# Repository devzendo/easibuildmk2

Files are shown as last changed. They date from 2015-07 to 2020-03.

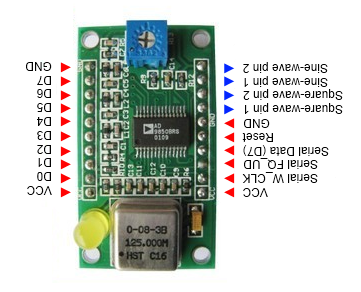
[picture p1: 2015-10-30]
docs/AD9850Pinout.png

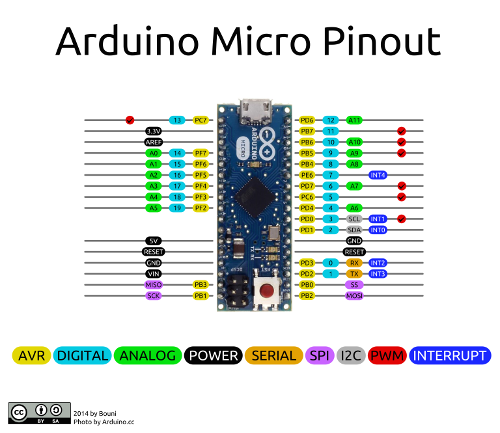
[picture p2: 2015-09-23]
docs/Arduino Micro Pinout Small.png

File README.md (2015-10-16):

# EasiBuild Mk II

This repository contains code and documentation for the EasiBuild Mk II low
power (QRP) amateur radio Morse code (CW: Continuous Wave) transceiver designed
by Matt Gumbley M0CUV based on an earlier design by Bruce Edwards G3WCE.

See https://mattgumbley.wordpress.com/category/amateur-radio/easibuild-mk-2/ for
the full set of blog articles on this project.

The code, diagrams, schematics and articles in this project are all licensed
under the Apache Public License, v2.

The Arduino IDE libraries in the Libraries folder are licensed under their own
licenses, please check the zip files there, and their respective websites,
details of which you'll find in the EasiBuildMk2.ino file.

To set up the libraries in the Arduino IDE:
1) SCoop. Create a folder called SCoop in your Arduino IDE's libraries folder
   (e.g. mine is ~/Documents/Arduino/libraries on OSX). Extract the 'SCoop V1.2
   New Year Pack.zip' file to a temporary folder, then copy SCoop/SCoop.{cpp|h}
   into the libraries/SCoop folder you created.
2) LiquidCrystal - can be added as a .zip library.
3) EnableInterrupt - don't know yet....

73 de M0CUV

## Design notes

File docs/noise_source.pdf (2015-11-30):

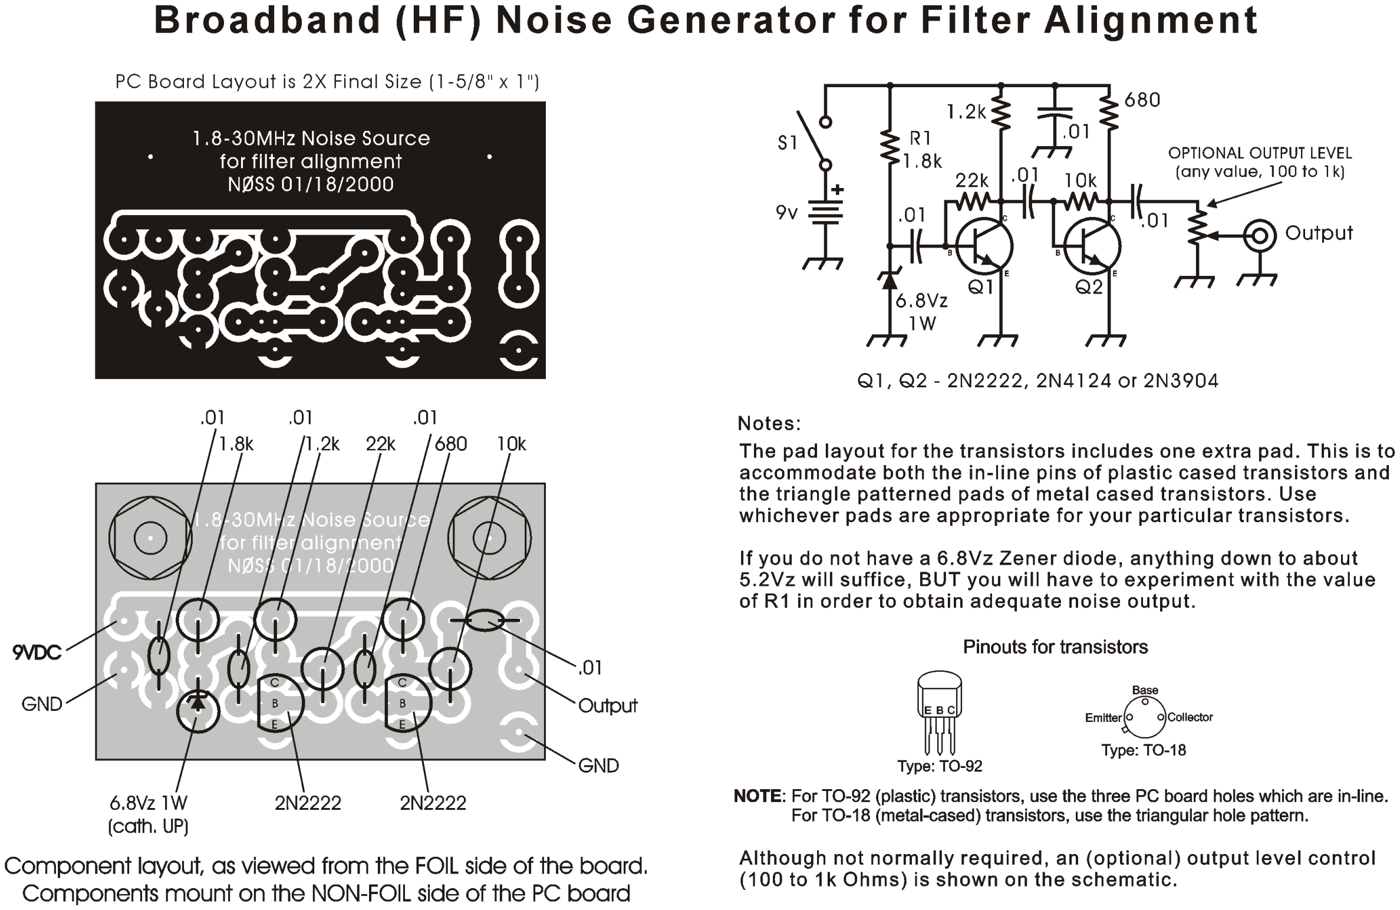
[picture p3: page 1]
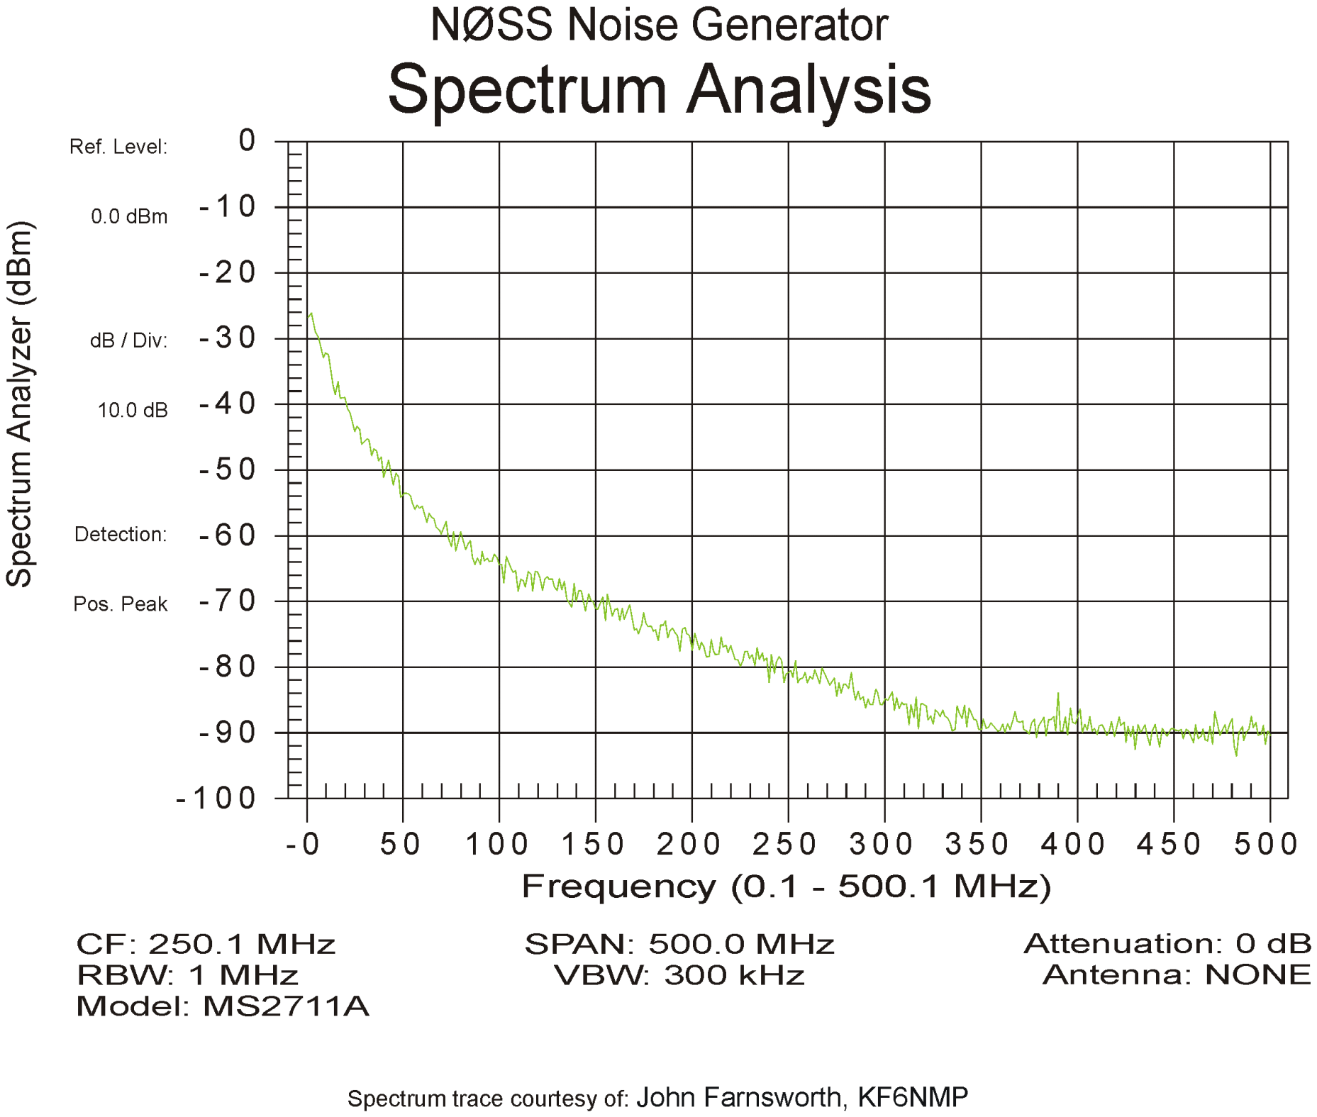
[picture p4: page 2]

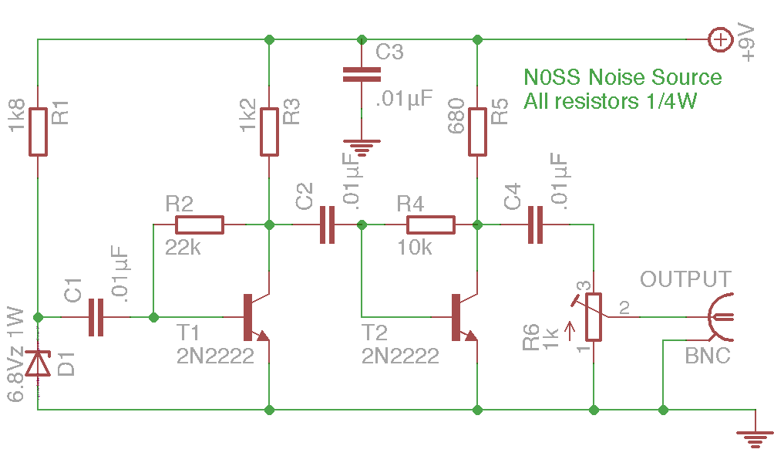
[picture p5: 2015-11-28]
docs/noise-source-schematic.png

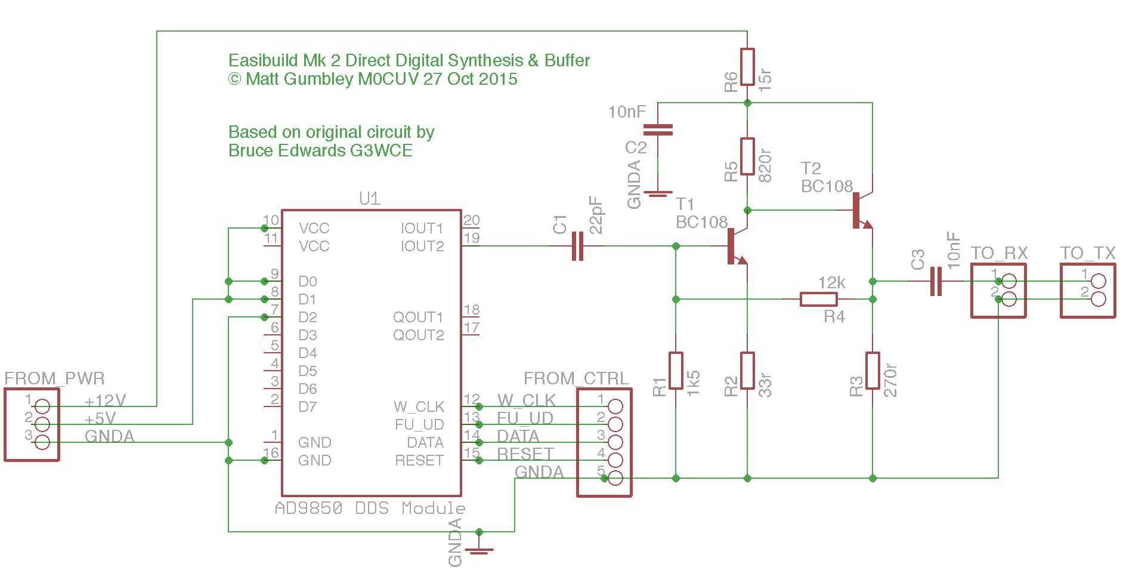
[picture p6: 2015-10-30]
docs/dds-schematic.png

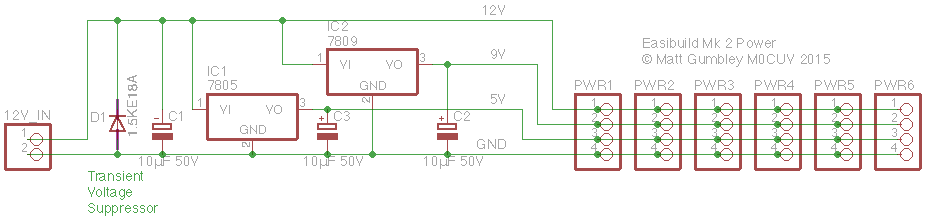
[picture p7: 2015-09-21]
docs/power-schematic.png

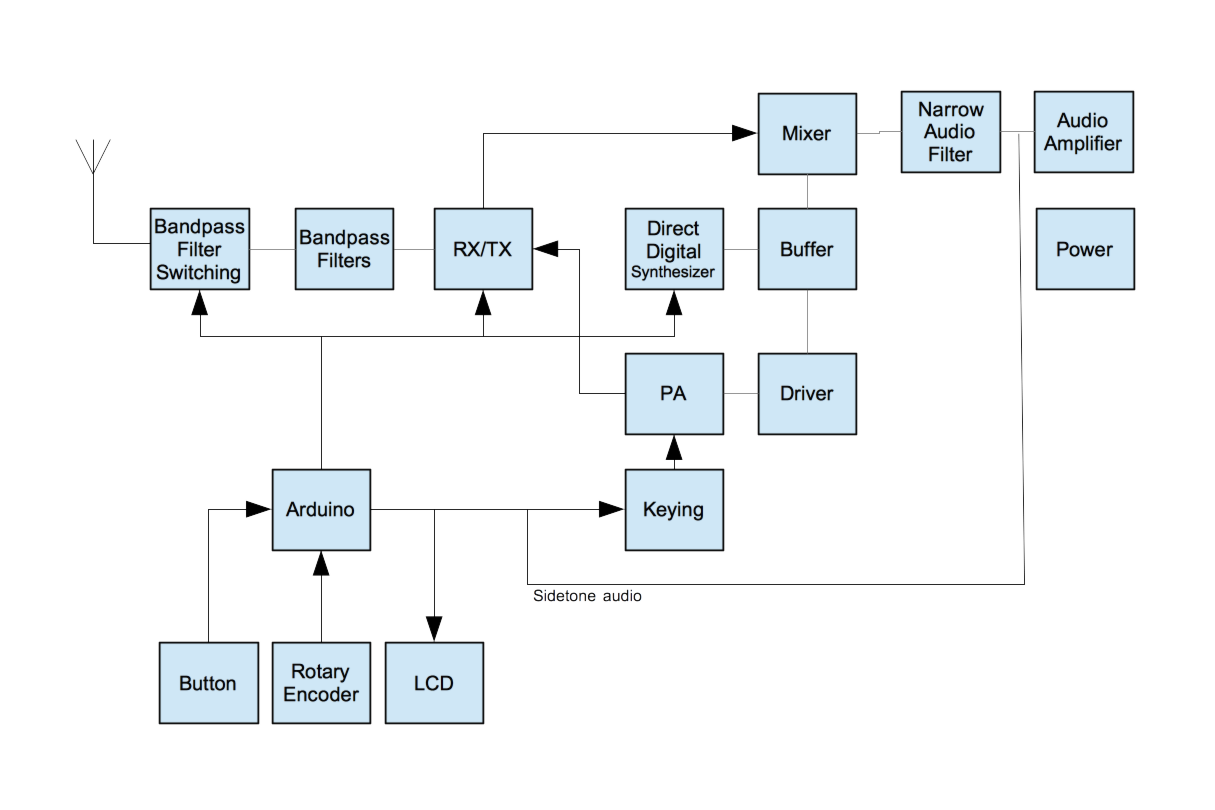
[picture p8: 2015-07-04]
docs/Overview Diagram.png

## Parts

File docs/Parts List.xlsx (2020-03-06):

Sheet: EasiBuild Mk 2
EasiBuild Mark 2 Parts | Orig EB part | Mk2 part | Supplier | Cost | Quantity | Total | Notes | URL
 |  |  |  |  |  | #N/A
Control & VFO:
Arduino Micro |  |  | Amazon/4tronix | £15.12 | 1 | £15.12 |  | http://4tronix.co.uk/store/index.php?rt=product/product&product_id=122
PEC16-4020F-S0024 |  |  | Mouser | £1.02 | 1 | £1.02 | Rotary encoder Mike N2HTT uses Bourns PEC16-4020F-S0024 Mouser 652-PEC16-4020FS0024 | http://uk.mouser.com/ProductDetail/Bourns/PEC16-4020F-S0024/
Silver metal knob |  |  | Proto-pic | £1.07 | 1 | £1.07 |  | http://proto-pic.co.uk/silver-metal-knob-14x24mm/
LCD |  |  | Amazon/inspiredeal limited | £1.19 | 1 | £1.19 |  | http://proto-pic.co.uk/serial-enabled-16x2-lcd-white-on-black-5v/
LCD SPI/I2C interface |  |  | Amazon/hielec | £1.10 | 1 | £1.10
Momentary tactile push button switch + cap |  |  | Amazon/sourcingmap | £0.24 | 0 | £0.00
16k 0.25W |  |  | Mouser | £0.09 | 1 | £0.09 | For PWM RC network to audio amp
10nF polyester |  |  | Mouser | £0.16 | 1 | £0.16 | For PWM RC network to audio amp
M20-7821046 |  |  |  | £0.11 | 6 | £0.66 | 10 pin female SIL socket (2 for DDS, 4 for Arduino)
74HC595 |  |  |  | £0.41 | 0 | £0.00
AD9850 DDS |  |  | eBay | £7.45 | 1 | £7.45 | From UK seller etang-uk
Buffer (not building this version): |  |  |  |  |  |  | number required when I build it v
22pF polystyrene | C5 |  |  | £0.00 | 0 | £0.00 | 1
BC108 | TR2 |  | Stock | £0.00 | 0 | £0.00 | 2
1k5 0.6W metal film | R5 |  |  | £0.10 | 0 | £0.00 | 1
10nF ceramic | C8 |  | Velleman | £0.10 | 0 | £0.00 | 2
15r 0.6W metal film | R3 |  |  | £0.10 | 0 | £0.00 | 1
820r 0.6W metal film | R4 |  |  | £0.10 | 0 | £0.00 | 1
33r 0.6W metal film | R6 |  |  | £0.10 | 0 | £0.00 | 1
12k 0.6W metal film | R7 |  |  | £0.10 | 0 | £0.00 | 1
270r 0.6W metal film | R8 |  |  | £0.10 | 0 | £0.00 | 1
Power supply:
Power coaxial jack |  |  | Mouser | £2.32 | 1 | £2.32 | Mouser 163-4304 - look elsewhere, maybe cheaper? Maplin JK09K £2.29 Proto-pic PPADA610 £2.71
Power mating plug |  |  | Mouser | £0.99 | 1 | £0.99 | Mouser 1710-2131 Maplin HH60Q is £1.99
10uF 50V elec |  |  | Stock | £0.00 | 3 | £0.00
LM7805CT |  |  |  | £0.48 | 1 | £0.48 | RS 671-0309
L7809CV |  |  | Stock | £0.00 | 1 | £0.00 | Farnell 1087089
1.5KE18ARL4G |  |  |  | £0.42 | 1 | £0.42
100nF ceramic | C43 |  | Velleman | £0.07 | 1 | £0.07 | Decoupling
5x20mm fuse holder |  |  |  | £0.70 | 1 | £0.70
1A Fuse |  |  |  | £0.13 | 1 | £0.13
Bandpass filter 160m/1.8MHz: | #REF!
x T50-2 |  |  |  | #N/A | 3 | #N/A
x 430pF close |  |  |  | #N/A | 2 | #N/A
x 560pF close |  |  |  | #N/A | 1 | #N/A
x 1800pF close |  |  |  | #N/A | 2 | #N/A
Bandpass filter 80m/3.5MHz: | #REF!
x T50-2 |  |  |  | #N/A | 3 | #N/A
x 130pF close |  |  |  | #N/A | 2 | #N/A
x 150pF close |  |  |  | #N/A | 1 | #N/A
x 910pF close |  |  |  | #N/A | 2 | #N/A
Bandpass filter 60m/5MHz: | #REF!
x T50-2 |  |  |  | #N/A | 3 | #N/A
x 47pF close |  |  |  | #N/A | 2 | #N/A
x 51pF close |  |  |  | #N/A | 1 | #N/A
x 620pF close |  |  |  | #N/A | 2 | #N/A
Bandpass filter 40m/7MHz: | £0.76
T50-2 |  |  |  | £0.14 | 3 | £0.43
39pF close |  |  |  | £0.15 | 2 | £0.31
39pF close |  |  |  | £0.15 | 1 | £0.15 | Should be 43pF but can't get those, so use 39pF + 4pF (1.5pF to 5pF) trimmer
1.5pF to 5pF Trimmer |  |  |  | £0.47 | 1 | £0.47
470pF close |  |  |  | £0.16 | 2 | £0.32
Bandpass filter 30m/10MHz: | £0.73
T50-2 |  |  |  | £0.14 | 3 | £0.43
16pF close |  |  |  | £0.21 | 3 | £0.63
330pF close |  |  |  | £0.15 | 2 | £0.29
Bandpass filter 20m/14MHz: | £0.94
T50-6 |  |  |  | £0.22 | 3 | £0.66
16pF close |  |  |  | £0.21 | 2 | £0.42
18pF close |  |  |  | £0.07 | 1 | £0.07
2.3pF to 27pF Trimmer |  |  |  | £1.79 | 1 | £1.79
220pF close |  |  |  | £0.14 | 2 | £0.28 | Should be 240pF but can't get those, so use 220pF + 20pF (2.3pF to 27pF) trimmer
Bandpass filter 17m/18MHz: | #N/A
x T50-6 |  |  |  | #N/A | 3 | #N/A
x 20pF close |  |  |  | #N/A | 2 | #N/A
x 24pF close |  |  |  | #N/A | 1 | #N/A
x 180pF close |  |  |  | #N/A | 2 | #N/A
Bandpass filter 15m/21MHz: | #N/A
x T50-6 |  |  |  | #N/A | 3 | #N/A
x 15pF close |  |  |  | #N/A | 2 | #N/A
x 16pF close |  |  |  | #N/A | 1 | #N/A
x 160pF close |  |  |  | #N/A | 2 | #N/A
Bandpass filter 12m/24MHz: | #N/A
x T50-6 |  |  |  | #N/A | 3 | #N/A
x 11pF close |  |  |  | #N/A | 2 | #N/A
x 12pF close |  |  |  | #N/A | 1 | #N/A
x 130pF close |  |  |  | #N/A | 2 | #N/A
Bandpass filter 10m/28MHz: | #N/A
x T50-6 |  |  |  | #N/A | 3 | #N/A
x 12pF close |  |  |  | #N/A | 2 | #N/A
x 13pF close |  |  |  | #N/A | 1 | #N/A
x 120pF close |  |  |  | #N/A | 2 | #N/A
Bandpass filter/T/R switching:
27k 0.25W |  |  |  | £0.08 | 1 | £0.08 | T/R: To reduce current from opto to transistor; coil resistance is 540r
270k 0.25W |  |  |  | £0.09 | 1 | £0.09 | T/R: Pull-down to prevent spurious triggering - 10x the base current resistor
13k 0.25W |  |  |  | £0.07 | 3 | £0.21 | Band: To reduce current from opto to two transistors; coil resistance is 540r
130k 0.25W |  |  |  | £0.09 | 3 | £0.28 | Band: Pull-down to prevent spurious triggering - 10x the base current resistor
470r 0.6W metal film |  |  |  | £0.10 | 5 | £0.49 | Band, T/R: From Arduino out to opto diode
4N25 |  |  |  | £0.31 | 5 | £1.55 | Band, T/R: Opto to control relay
DIP-6-Socket |  |  |  | £0.16 | 5 | £0.82
1N4001 |  |  |  | £0.02 | 7 | £0.14 | To prevent back e.m.f. from relay coil
BC547B |  |  |  | £0.05 | 7 | £0.35 | Band, T/R: each band has 2 relays (2x3) plus one for T/R
V23105A5006A201 |  |  |  | £1.34 | 7 | £9.38 | 9v, 150mW, coil resistance 540Ohm, DPDT
Mixer:
NE612 | IC3 |  |  | £1.88 | 1 | £1.88 | In a pack of 2 | http://uk.rs-online.com/web/p/up-down-converter-mixer-circuits/7257613/
DIP-8-socket |  |  | Stock | £0.00 | 1 | £0.00
100pF ceramic | C13 |  | Velleman | £0.00 | 1 | £0.00 | Ceramic plate
10nF ceramic | C14,C17,C20,C21 |  | Velleman | £0.10 | 4 | £0.39 | Ceramic disc - wonder if C17 should be polyester as it's audio?
22pF polystyrene | C15 |  |  | £0.00 | 1 | £0.00 | Polystyrene
1uF 16V elec | C16 |  |  | £0.02 | 1 | £0.02 | 16V electrolytic
1mH | RFC2 |  |  | £0.12 | 1 | £0.12
78L08 | IC2 |  | Stock | £0.00 | 1 | £0.00 | 8v? Supply
Hi-Per-Mite filter/amplifier:
100nF ceramic | C1,C10,C11,C15 |  | Velleman | £0.07 | 4 | £0.26 | Ceramic 104
1nF polyester | C4,C6,C9 |  |  | £0.18 | 3 | £0.54 | Polyester .001u or 1n0
220uF 16V elec | C12,C13,C14 |  |  | £0.06 | 3 | £0.18 | Elec
2n2 polyester | C7,C8 |  |  | £0.16 | 2 | £0.32 | Polyester .0022u
10pF ceramic | C16 |  | Velleman | £0.00 | 1 | £0.00 | Ceramic
47nF polyester | C2 |  |  | £0.16 | 1 | £0.16 | Polyester .047u
39nF polyester | C5 |  |  | £0.25 | 1 | £0.25 | Polyester .039u
36nF polyester | C3 |  |  | £1.85 | 1 | £1.85 | Polyester .036u
33k 5% | R1 |  |  | £0.08 | 1 | £0.08 | 5% resistors, these are for 640Hz
36k 5% | R2 |  |  | £0.09 | 1 | £0.09
1M 5% | R3 |  |  | £0.07 | 1 | £0.07
51k 5% | R4,R5 |  |  | £0.08 | 2 | £0.16
39k 5% | R6,R7 |  |  | £0.07 | 2 | £0.14
11k 5% | R8 |  |  | £0.07 | 1 | £0.07
820k 5% | R9 |  |  | £0.09 | 1 | £0.09
10r 5% | R10 |  |  | £0.07 | 1 | £0.07
10k 5% | R14 |  |  | £0.07 | 1 | £0.07
100k log pot + switch |  |  |  | £0.63 | 1 | £0.63
TLC274CN |  |  |  | £0.69 | 1 | £0.69
LM386 |  |  |  | £0.66 | 1 | £0.66
DIP-14-socket |  |  | Stock | £0.00 | 1 | £0.00
DIP-8-socket |  |  | Stock | £0.00 | 1 | £0.00
Transmitter:
10nF ceramic | C27,C28,C30,C31,C32 |  | Velleman | £0.10 | 5 | £0.49
1k 0.6W metal film | R15 |  |  | £0.10 | 1 | £0.10
220r 0.6W metal film | R16 |  |  | £0.10 | 1 | £0.10
BFY51 | TR5,TR6 |  | Stock | £0.00 | 2 | £0.00
56r 0.6W metal film | R18 |  |  | £0.10 | 1 | £0.10
47r 0.6W metal film | R17 |  |  | £0.10 | 1 | £0.10
T50-2 | L2 |  |  | £0.14 | 1 | £0.14
150pF ceramic | C29 |  |  | £0.02 | 1 | £0.02
2u2 ceramic | C36 |  |  | £1.79 | 1 | £1.79
33r 0.6W metal film | R19 |  |  | £0.10 | 1 | £0.10
2N2905 | TR7 |  | Stock | £0.00 | 1 | £0.00
FB | RFC3 |  | Stock | £0.00 | 1 | £0.00
1k 0.6W metal film | R20 |  |  | £0.10 | 1 | £0.10
4N25 |  |  |  | £0.31 | 1 | £0.31
TO-39 Heatsink |  |  |  | £0.30 | 1 | £0.30
DIP-6-Socket |  |  |  | £0.16 | 1 | £0.16
470r 0.6W metal film |  |  |  | £0.10 | 1 | £0.10 | From Arduino out to opto diode
PVC covererd link wire |  |  | Stock | £0.00 | 1 | £0.00
0.56mm wire |  |  | Stock | £0.00 | 1 | £0.00
0.375mm wire |  |  | Stock | £0.00 | 1 | £0.00
Miscellaneous:
Nuts, Bolts |  |  |  |  |  | £0.00
Enclosure |  |  |  |  |  | £0.00
Matrix board |  |  |  |  |  | £0.00
Stripboard |  |  |  |  |  | £0.00
3.5mm stereo socket |  |  |  | £0.45 | 2 | £0.90 | For key/paddle, and audio out | http://uk.mouser.com/ProductDetail/Kobiconn/161-3402-E/?qs=sGAEpiMZZMv0W4pxf2HiV4Mt5ZQSVq1hAasLUHlfK30%3d
BNC socket |  |  |  | £0.85 | 1 | £0.85
N0SS Noise Generator:
Enclosure |  |  |  |  |  | £0.00
On/Off Switch |  |  |  |  |  | £0.00
PP3 Battery Connector |  |  |  |  |  | £0.00
1k8 0.25W |  |  |  | £0.08 | 1 | £0.08
1k2 0.25W |  |  |  | £0.08 | 1 | £0.08
680r 0.25W |  |  |  | £0.08 | 1 | £0.08
22k 0.25W |  |  |  | £0.08 | 1 | £0.08
10k 0.25W |  |  |  | £0.07 | 1 | £0.07
1k preset |  |  | Stock | £0.00 | 1 | £0.00
10nF ceramic |  |  | Stock | £0.10 | 4 | £0.39
2N2222A |  |  |  | £0.13 | 2 | £0.26
BNC socket |  |  |  | £0.85 | 1 | £0.85
6.8Vz |  |  |  | £0.15 | 1 | £0.15
Signal attenuator (not building yet): |  |  |  |  |  | £0.00 | v Total number of resistors number required when I build it v
BNC socket |  |  |  | £0.85 | 2 | £1.70 | 0
DPDT switch |  |  |  | £0.72 | 6 | £4.32
47n |  |  | Velleman | £0.00 | 0 | £0.00 | 1
6r8 0.25W |  |  |  | £0.08 | 0 | £0.00 | 8
22r 0.25W |  |  |  | £0.08 | 0 | £0.00 | 5
470r 0.25W |  |  |  | £0.09 | 0 | £0.00 | 1
5k6 0.25W |  |  |  | £0.08 | 0 | £0.00 | 1
100r 0.25W |  |  |  | £0.07 | 0 | £0.00 | 4
68r 0.25W |  |  |  | £0.09 | 0 | £0.00 | 7
220r 0.25W |  |  |  | £0.09 | 0 | £0.00 | 5
10k 0.25W |  |  |  | £0.07 | 0 | £0.00 | 1
12r 0.25W |  |  |  | £0.08 | 0 | £0.00 | 3
2k2 0.25W |  |  |  | £0.08 | 0 | £0.00 | 2
120r 0.25W |  |  |  | £0.08 | 0 | £0.00 | 1
1k 0.25W |  |  |  | £0.07 | 0 | £0.00 | 3
4k7 0.25W |  |  |  | £0.09 | 0 | £0.00 | 1
56r 0.25W |  |  |  | £0.09 | 0 | £0.00 | 1
330r 0.25W |  |  |  | £0.09 | 0 | £0.00 | 3
820r 0.25W |  |  |  | £0.09 | 0 | £0.00 | 1
3k9 0.25W |  |  |  | £0.09 | 0 | £0.00 | 1
560r 0.25W |  |  |  | £0.09 | 0 | £0.00 | 2
47r 0.25W |  |  |  | £0.08 | 0 | £0.00 | 1
Enclosure |  |  |  |  |  | £0.00
SWR analyser version 2 (not building yet): |  |  |  |  |  | £0.00 | number required when I build it v
50r 1W | R1,R2,R3 |  |  | £0.32 | 0 | £0.00 | 3
100k | R5,R9 |  |  | #N/A | 0 | #N/A | 2
5k | R6,R10 |  |  | #N/A | 0 | #N/A | 2
22k | R6,R10 (alt) |  |  | #N/A | 0 | #N/A | 2
10k | R4,R8 |  |  | #N/A | 0 | #N/A | 2
649r 0.25W 5% 50PPM | R7,R11 |  |  | #N/A | 0 | #N/A | 2
0.1uF elec | C1 |  |  | #N/A | 0 | #N/A | 1
100nF ceramic | C2,C4 |  |  | £0.07 | 0 | £0.00 | 2
10nF ceramic | C3,C5,C6 |  |  | £0.10 | 0 | £0.00 | 3
MCP6002 | U2 |  |  | £0.00 | 0 | £0.00 | 1
Dummy load and attenuator
BNC socket |  |  |  | £0.85 | 2 | £1.70
100r 5w 5% metal oxide film |  |  |  | £0.82 | 2 | £1.64
620r 2% 0.5w metal film |  |  |  | £0.21 | 4 | £0.84
100r 2% 0.5w metal film |  |  |  | £0.21 | 2 | £0.42
W5DOR buffer components |  |  |  |  |  | £0.00
27r 0.6W metal film | R7 |  |  | £0.10 | 1 | £0.10
100nF ceramic | C1,C2,C3 |  | Velleman | £0.07 | 3 | £0.20 | 100nF = 0.1uF
1k 0.6W metal film | R3 |  |  | £0.10 | 1 | £0.10
47r 0.6W metal film | R2 |  |  | £0.10 | 1 | £0.10
2N2222A | Q1,Q2 |  |  | £0.13 | 2 | £0.26
120r 0.6W metal film | R4 |  |  | £0.10 | 1 | £0.10
620r 0.5W metal film | R6 |  |  | £0.13 | 1 | £0.13 | 0.6W not available
470r 0.6W metal film | R5 |  |  | £0.10 | 1 | £0.10
Brainwagon buffer components |  |  |  |  |  | £0.00 | number required when I build it v
220r 0.6W metal film | R5 |  |  |  | 0 |  | 1
0.1uF ceramic | C1,C2 |  |  |  | 0 |  | 2
560r 0.6W metal film | R4 |  |  |  | 0 |  | 1
470r 0.6W metal film | R1 |  |  |  | 0 |  | 1
220r 0.6W metal film | R7 |  |  |  | 0 |  | 1
82r 0.6W metal film | R2 |  |  |  | 0 |  | 1
2r2 0.6W metal film | R3 |  |  |  | 0 |  | 1
50r 0.6W metal film | R6 |  |  |  | 0 |  | 1
2N2222A | Q1,Q2 |  |  |  | 0 |  | 2
Miscellaneous/stock building extras |  |  |  |  |  | £0.00
pcb sanding block |  |  |  | £3.36 |  | £0.00 |  | http://uk.rs-online.com/web/p/pcb-cleaning-scrub-blocks/2162706/
LM7805CT |  |  |  | £0.48 | 2 | £0.96
1.5KE18ARL4G |  |  |  | £0.42 | 2 | £0.85
1A Fuse |  |  |  | £0.13 | 4 | £0.52
 |  |  |  |  |  | £0.00
 |  |  |  |  |  | £0.00
 |  |  |  |  |  | £0.00
 |  |  |  |  |  | £0.00
 |  |  |  |  |  | £0.00
 |  |  |  |  |  | £0.00
 |  |  |  |  |  | £0.00
 |  |  |  |  |  | £0.00
 |  |  |  |  |  | £0.00
 |  |  |  |  |  | £0.00
 |  |  |  |  |  | £0.00
 |  |  |  |  |  | £0.00
 |  |  |  |  |  | £0.00
 |  |  |  |  |  | £0.00
 |  |  |  |  |  | £0.00
 |  |  |  |  |  | £0.00
 |  |  |  |  |  | £0.00
 |  |  |  |  |  | £0.00
 |  |  |  |  |  | £0.00
 |  |  |  |  |  | £0.00
 |  |  |  |  |  | £0.00

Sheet: Component Costs
Value | Cost | Supplier | Quantity to order | Total Cost | Notes | URL
Electrolytic capacitors | £0.00 | None
1uF 16V elec | £0.02 | CPC Farnell | 1 | £0.02 | Get a few - they seem rare - check in stock (min order 25, but cheap enough) | http://cpc.farnell.com/unbranded/np16v105m5x11/capacitor-n-p-1-0uf-16v/dp/CA05943?categoryId=700000011529
220uF 16V elec | £0.06 | CPC Farnell | 3 | £0.18 | min order 5 | http://cpc.farnell.com/multicomp/mcmr16v227m8x7/capacitor-220uf-16v-radial-7mm/dp/CA08168
10uF 50V elec | £0.00 | Stock | 3 | £0.00
Capacitors | £0.00 | None
Trimmer | £1.56 | Mouser | 0 | £0.00 | 2.2pF to 22pF 100V | http://uk.mouser.com/ProductDetail/Sprague-Goodman/GYA22000/
1.5pF to 5pF Trimmer | £0.47 | Mouser | 1 | £0.47 |  | http://uk.mouser.com/ProductDetail/Murata-Electronics/TZ03Z050N169B00/
2.3pF to 27pF Trimmer | £1.79 | Mouser | 1 | £1.79 |  | http://uk.mouser.com/ProductDetail/Sprague-Goodman/GYA27000/
1nF polyester | £0.18 | Mouser | 3 | £0.54 | 0.001uF 1000pF | http://uk.mouser.com/ProductDetail/Kemet/R82EC1100AA50J/
22pF polystyrene | £0.00 | Stock | 1 | £0.00 |  | http://cpc.farnell.com/lcr-components/fsc-160v-22pf-1pf/capacitor-160v-22pf/dp/CA05848?categoryId=700000011519
2n2 polyester | £0.16 | Mouser | 2 | £0.32 | 0.0022uF 2200pF | http://uk.mouser.com/ProductDetail/Kemet/R82MC1220AA50J/
10nF polyester | £0.16 | Mouser | 1 | £0.16 | 0.01uF | http://uk.mouser.com/ProductDetail/Kemet/R82EC2100AA50J/
47nF polyester | £0.16 | Mouser | 1 | £0.16 | 0.047uF | http://uk.mouser.com/ProductDetail/Kemet/R82EC2470AA60J/
39nF polyester | £0.25 | Mouser | 1 | £0.25 | 0.039uF | http://uk.mouser.com/ProductDetail/Panasonic/ECQ-E2393JF/
36nF polyester | £1.85 | Mouser | 1 | £1.85 | 0.036uF | http://uk.mouser.com/ProductDetail/Vishay/BFC241643603/
2u2 ceramic | £1.79 | Mouser | 1 | £1.79 | 2200nF | http://uk.mouser.com/ProductDetail/Kemet/C430C225K5R5TA/
10nF ceramic | £0.10 | In Velleman set | 13 | £1.27 |  | http://uk.mouser.com/ProductDetail/Vishay-Sprague/1C10Z5U103M050B/
100nF ceramic | £0.07 | In Velleman set | 8 | £0.53 |  | http://uk.mouser.com/ProductDetail/Vishay-Sprague/1C10Z5U104M050B/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
10pF ceramic | £0.00 | In Velleman set | 1 | £0.00
100pF ceramic | £0.00 | In Velleman set | 1 | £0.00
150pF ceramic | £0.02 | CPC Farnell | 1 | £0.02 | £0.24 for a pack of 10 | http://cpc.farnell.com/multicomp/mcchu8151j5/capacitor-150pf-50v/dp/CA06306
11pF close | £0.00 | Unknown | 0 | £0.00 |  | close means 100V good tolerance RF ceramic
12pF close | £0.00 | Unknown | 0 | £0.00
13pF close | £0.00 | Unknown | 0 | £0.00
15pF close | £0.00 | Unknown | 0 | £0.00
16pF close | £0.21 | Mouser | 5 | £1.05 |  | http://uk.mouser.com/ProductDetail/AVX/SR151A160JAR/?qs=G2E3TvrFun24hZu%252bwlfrfg%3d%3d
18pF close | £0.07 | Mouser | 1 | £0.07 |  | http://uk.mouser.com/ProductDetail/AVX/SR151A180JAR/
20pF close | £0.00 | Unknown | 0 | £0.00
24pF close | £0.00 | Unknown | 0 | £0.00
39pF close | £0.15 | Mouser | 3 | £0.46 |  | http://uk.mouser.com/ProductDetail/AVX/SR151A390JAR/
43pF close | £0.00 | Unobtainable | 0 | £0.00
47pF close | £0.00 | Unknown | 0 | £0.00
51pF close | £0.00 | Unknown | 0 | £0.00
120pF close | £0.00 | Unknown | 0 | £0.00
130pF close | £0.00 | Unknown | 0 | £0.00
150pF close | £0.00 | Unknown | 0 | £0.00
160pF close | £0.00 | Unknown | 0 | £0.00
180pF close | £0.00 | Unknown | 0 | £0.00
220pF close | £0.14 | Mouser | 2 | £0.28 |  | http://uk.mouser.com/ProductDetail/AVX/SR151A221JAR/?qs=sGAEpiMZZMt3KoXD5rJ2N2to1Wh0ElM26jzESq0OTWI%3d
240pF close | £0.00 | Unobtainable | 0 | £0.00
330pF close | £0.15 | Mouser | 2 | £0.29 |  | http://uk.mouser.com/ProductDetail/AVX/SR151A331JAR/?qs=sGAEpiMZZMt3KoXD5rJ2N7PtT0SQbQfdEjRnghX6gSs%3d
430pF close | £0.00 | Unknown | 0 | £0.00
470pF close | £0.16 | Mouser | 2 | £0.32 |  | http://uk.mouser.com/ProductDetail/AVX/SA051A471JAR/?qs=sGAEpiMZZMuMW9TJLBQkXtuSvlMoo6ldmJYgsExi9pI%3d
560pF close | £0.00 | Unknown | 0 | £0.00
620pF close | £0.00 | Unknown | 0 | £0.00
910pF close | £0.00 | Unknown | 0 | £0.00
1800pF close | £0.00 | Unknown | 0 | £0.00
Resistors | £0.00 | None
6r8 0.25W | £0.08 | Mouser | 0 | £0.00 |  | http://uk.mouser.com/ProductDetail/KOA-Speer/MF1-4DCT52R6R80F/
10r 5% | £0.07 | Mouser | 1 | £0.07 |  | http://uk.mouser.com/ProductDetail/Yageo/MFR-25FBF52-10R/
12r 0.25W | £0.08 | Mouser | 0 | £0.00 |  | http://uk.mouser.com/ProductDetail/KOA-Speer/MFS1-4DCT52R12R0F/
15r 0.6W metal film | £0.10 | Mouser | 0 | £0.00 |  | http://uk.mouser.com/ProductDetail/TE-Connectivity/LR1F15R/?qs=ip69W3eHERXAiaIcuBY1og%3d%3d
22r 0.25W | £0.08 | Mouser | 0 | £0.00 |  | http://uk.mouser.com/ProductDetail/Yageo/MFR-25FTE52-22R/?qs=sGAEpiMZZMsPqMdJzcrNwiweiCzxKzWL05FsoZ6xF5k%3d
27r 0.6W metal film | £0.10 | Mouser | 1 | £0.10 |  | http://uk.mouser.com/ProductDetail/TE-Connectivity/LR1F27R/?qs=ip69W3eHERU80cCHlxDX0g%3d%3d
33r 0.6W metal film | £0.10 | Mouser | 1 | £0.10 |  | http://uk.mouser.com/ProductDetail/TE-Connectivity/LR1F33R/?qs=ip69W3eHERXJBF1EX4msog%3d%3d
47r 0.25W | £0.08 | Mouser | 0 | £0.00 |  | http://uk.mouser.com/ProductDetail/KOA-Speer/MFS1-4DCT52R47R0F/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
47r 0.6W metal film | £0.10 | Mouser | 2 | £0.20 |  | http://uk.mouser.com/ProductDetail/TE-Connectivity/LR1F47R/?qs=ip69W3eHERUjMhpCvjXiww%3d%3d
50r 1W | £0.32 | Mouser | 0 | £0.00 |  | http://uk.mouser.com/ProductDetail/Vishay-Dale/CPF150R000FEE14/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
56r 0.6W metal film | £0.10 | Mouser | 1 | £0.10 |  | http://uk.mouser.com/ProductDetail/TE-Connectivity/LR1F56R/?qs=ip69W3eHERWLNQcgiYR7kA%3d%3d
56r 0.25W | £0.09 | Mouser | 0 | £0.00 |  | http://uk.mouser.com/ProductDetail/KOA-Speer/MF1-4DCT52R56R0F/
68r 0.25W | £0.09 | Mouser | 0 | £0.00 |  | http://uk.mouser.com/ProductDetail/KOA-Speer/MF1-4DCT52R68R0F/
100r 5w 5% metal oxide film | £0.82 | Mouser | 2 | £1.64 |  | http://uk.mouser.com/ProductDetail/KOA-Speer/MOS5C101J/
100r 2% 0.5w metal film | £0.21 | Mouser | 2 | £0.42 |  | http://uk.mouser.com/ProductDetail/Vishay-Dale/RL20S101GB14/
100r 0.25W | £0.07 | Mouser | 0 | £0.00 |  | http://uk.mouser.com/ProductDetail/Yageo/MFR-25FBF52-100R/
120r 0.6W metal film | £0.10 | Mouser | 1 | £0.10 |  | http://uk.mouser.com/ProductDetail/TE-Connectivity/LR1F120R/?qs=ip69W3eHERVVN0%2faPZ4FyA%3d%3d
120r 0.25W | £0.08 | Mouser | 0 | £0.00 |  | http://uk.mouser.com/ProductDetail/KOA-Speer/MFS1-4DCT52R1200F/
220r 0.25W | £0.09 | Mouser | 0 | £0.00 |  | http://uk.mouser.com/ProductDetail/Yageo/MFR-25FRF52-220R/?qs=sGAEpiMZZMsPqMdJzcrNwiweiCzxKzWLiIp2BUlcs7w%3d
220r 0.6W metal film | £0.10 | Mouser | 1 | £0.10 |  | http://uk.mouser.com/ProductDetail/TE-Connectivity/LR1F220R/?qs=ip69W3eHERVejNQBGjgYsQ%3d%3d
270r 0.6W metal film | £0.10 | Mouser | 0 | £0.00 |  | http://uk.mouser.com/ProductDetail/TE-Connectivity/LR1F270R/?qs=ip69W3eHERVdh4KsKGQZHg%3d%3d
330r 0.25W | £0.09 | Mouser | 0 | £0.00 |  | http://uk.mouser.com/ProductDetail/Yageo/MFR-25FTE52-330R/
470r 0.6W metal film | £0.10 | Mouser | 7 | £0.69 |  | http://uk.mouser.com/ProductDetail/TE-Connectivity/LR1F470R/?qs=ip69W3eHERXVS%2f1ithav3g%3d%3d
470r 0.25W | £0.09 | Mouser | 0 | £0.00 |  | http://uk.mouser.com/ProductDetail/Yageo/MFR-25FRF52-470R/
560r 0.25W | £0.09 | Mouser | 0 | £0.00 |  | http://uk.mouser.com/ProductDetail/Yageo/MFR-25FBF52-560R/
620r 0.5W metal film | £0.13 | Mouser | 1 | £0.13 |  | http://uk.mouser.com/ProductDetail/Yageo/MFR50SFTE52-620R/
620r 2% 0.5w metal film | £0.21 | Mouser | 4 | £0.84 |  | http://uk.mouser.com/ProductDetail/Vishay-Dale/RL20S621GB14/?qs=sGAEpiMZZMtG0KNrPCHnjVJFrQ1zkYeo6WTPWoMhBU8%3d
680r 0.25W | £0.08 | Mouser | 1 | £0.08 |  | http://uk.mouser.com/ProductDetail/KOA-Speer/MF1-4LCT52R681J/
820r 0.25W | £0.09 | Mouser | 0 | £0.00 |  | http://uk.mouser.com/ProductDetail/Yageo/MFR-25FBF52-820R/?qs=sGAEpiMZZMsPqMdJzcrNwiweiCzxKzWLLuACzKO9H8U%3d
820r 0.6W metal film | £0.10 | Mouser | 0 | £0.00 |  | http://uk.mouser.com/ProductDetail/TE-Connectivity/LR1F820R/?qs=ip69W3eHERXnEpAgCZKZDQ%3d%3d
1k 0.6W metal film | £0.10 | Mouser | 3 | £0.29 |  | http://uk.mouser.com/ProductDetail/TE-Connectivity/LR1F1K0/?qs=ip69W3eHERVhMxNSZkerTg%3d%3d
1k 0.25W | £0.07 | Mouser | 0 | £0.00 |  | http://uk.mouser.com/ProductDetail/KOA-Speer/MF1-4LCT52R102J/
1k2 0.25W | £0.08 | Mouser | 1 | £0.08 |  | http://uk.mouser.com/ProductDetail/KOA-Speer/MF1-4LCT52R122J/
1k5 0.6W metal film | £0.10 | Mouser | 0 | £0.00 |  | http://uk.mouser.com/ProductDetail/TE-Connectivity/LR1F1K5/?qs=ip69W3eHERWeVkC3Rc8WnA%3d%3d
1k8 0.25W | £0.08 | Mouser | 1 | £0.08 |  | http://uk.mouser.com/ProductDetail/KOA-Speer/MF1-4LCT52R182G/
2k2 0.25W | £0.08 | Mouser | 0 | £0.00 |  | http://uk.mouser.com/ProductDetail/KOA-Speer/MFS1-4DCT52R2201F/
3k9 0.25W | £0.09 | Mouser | 0 | £0.00 |  | http://uk.mouser.com/ProductDetail/Yageo/MFR-25FRF52-3K9/?qs=sGAEpiMZZMsPqMdJzcrNwiweiCzxKzWL1b5QcO7Z0uA%3d
4k7 0.25W | £0.09 | Mouser | 0 | £0.00 |  | http://uk.mouser.com/ProductDetail/Yageo/MFR-25FRF52-4K7/?qs=sGAEpiMZZMsPqMdJzcrNwiweiCzxKzWLSmOYyQgL5OQ%3d
5k6 0.25W | £0.08 | Mouser | 0 | £0.00 |  | http://uk.mouser.com/ProductDetail/KOA-Speer/MFS1-4DCT52R5601F/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
10k 0.25W | £0.07 | Mouser | 1 | £0.07 |  | http://uk.mouser.com/ProductDetail/Yageo/MFR-25FRF52-10K/
10k 5% | £0.07 | Mouser | 1 | £0.07 |  | http://uk.mouser.com/ProductDetail/Yageo/MFR-25FRF52-10K/
11k 5% | £0.07 | Mouser | 1 | £0.07 |  | http://uk.mouser.com/ProductDetail/Yageo/MFR-25FBF52-11K/?qs=sGAEpiMZZMsPqMdJzcrNwiweiCzxKzWLkfMDDlq4H58%3d
12k 0.6W metal film | £0.10 | Mouser | 0 | £0.00 |  | http://uk.mouser.com/ProductDetail/TE-Connectivity/LR1F12K/?qs=ip69W3eHERUWzk9kJLfQiQ%3d%3d
13k 0.25W | £0.07 | Mouser | 3 | £0.21 |  | http://uk.mouser.com/ProductDetail/Yageo/MFR-25FRF52-13K/?qs=sGAEpiMZZMsPqMdJzcrNwiweiCzxKzWLtZYyyYSUqX8%3d
16k 0.25W | £0.09 | Mouser | 1 | £0.09 |  | http://uk.mouser.com/ProductDetail/KOA-Speer/MF1-4DCT52R1602F/
22k 0.25W | £0.08 | Mouser | 1 | £0.08 |  | http://uk.mouser.com/ProductDetail/KOA-Speer/MF1-4LCT52R223G/
27k 0.25W | £0.08 | Mouser | 1 | £0.08 |  | http://uk.mouser.com/ProductDetail/KOA-Speer/MF1-4LCT52R273G/
33k 5% | £0.08 | Mouser | 1 | £0.08 |  | http://uk.mouser.com/ProductDetail/KOA-Speer/MF1-4LCT52R333J/
36k 5% | £0.09 | Mouser | 1 | £0.09 |  | http://uk.mouser.com/ProductDetail/KOA-Speer/MF1-4DCT52R3602F/
39k 5% | £0.07 | Mouser | 2 | £0.14 |  | http://uk.mouser.com/ProductDetail/Vishay-BC-Components/SFR16S0003902JA500/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
51k 5% | £0.08 | Mouser | 2 | £0.16 |  | http://uk.mouser.com/ProductDetail/KOA-Speer/MF1-4LCT52R513G/
130k 0.25W | £0.09 | Mouser | 3 | £0.28 |  | http://uk.mouser.com/ProductDetail/KOA-Speer/MF1-4DC1303F/?qs=sGAEpiMZZMsPqMdJzcrNwlIzJk2YGEV83hDeXEq1E7E%3d
160k 0.25W | £0.09 | Mouser | 0 | £0.00 |  | http://uk.mouser.com/ProductDetail/Yageo/MFR-25FRF52-160K/?qs=sGAEpiMZZMsPqMdJzcrNwiweiCzxKzWLKp1bNII2Nvk%3d
270k 0.25W | £0.09 | Mouser | 1 | £0.09 |  | http://uk.mouser.com/ProductDetail/Yageo/MFR-25FTE52-270K/?qs=sGAEpiMZZMsPqMdJzcrNwiweiCzxKzWLIMXg3W78tiM%3d
820k 5% | £0.09 | Mouser | 1 | £0.09 |  | http://uk.mouser.com/ProductDetail/Yageo/MFR-25FTE52-820K/
1M 5% | £0.07 | Mouser | 1 | £0.07 |  | http://uk.mouser.com/ProductDetail/Yageo/MFR-25FRF52-1M/
Semiconductors | £0.00 | None
BC108 | £0.00 | Stock | 0 | £0.00 | CPC do min order 5, 0.22ea
1N4007 | £0.02 | Bowood | 0 | £0.00 | £1 for a bag of 50
LM386 | £0.66 | Mouser | 1 | £0.66 |  | http://uk.mouser.com/ProductDetail/Texas-Instruments/LM386N-4-NOPB/
NE612 | £1.88 | RS | 1 | £1.88 | In a pack of 2 - get several packs | http://uk.rs-online.com/web/p/up-down-converter-mixer-circuits/7257613/
LM7805CT | £0.48 | Mouser | 3 | £1.45 | RS was cheapest | http://uk.mouser.com/ProductDetail/Fairchild-Semiconductor/LM7805CT/
L7809CV | £0.00 | Stock | 1 | £0.00 | CPC 0.23
78L08 | £0.00 | Stock | 1 | £0.00 | Mouser 0.25 | http://uk.mouser.com/ProductDetail/STMicroelectronics/L78L08ACZ/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
TLC274CN | £0.69 | CPC Farnell | 1 | £0.69 | CN variant | http://cpc.farnell.com/texas-instruments/tlc274cn/op-amp-quad-cmos-dip14-274/dp/SC07945?ost=TLC274CN
BC547B | £0.05 | Bowood | 7 | £0.35 | £1 for a bag of 20
2N2222A | £0.13 | CPC Farnell | 4 | £0.52 | min 5. (JAB 10 for £3.60) (Bowood £0.40 ea) (£0.13 ea, min 5, CPC) (£0.29 ea RS) (Mouser expensive) | http://cpc.farnell.com/unbranded/2n2222a/transistor-npn-to-18/dp/SC06714
1N4001 | £0.02 | Bowood | 7 | £0.14 | £1 for a bag of 50
4N25 | £0.31 | RS | 6 | £1.86 | Bowood 0.45; Mouser 0.418; RS 0.31 | http://uk.rs-online.com/web/p/optocouplers/0597289/
2N2905 | £0.00 | Stock | 1 | £0.00 | Bowood 0.40
BFY51 | £0.00 | Stock | 2 | £0.00 | Bowood 0.50
74HC595 | £0.41 | RS | 0 | £0.00 |  | http://uk.rs-online.com/web/p/counters-shift-registers/2175695/
MCP6002 | £0.00 | Stock | 0 | £0.00
1.5KE18ARL4G | £0.42 | Mouser | 3 | £1.27 | Transient suppressor diode | http://uk.mouser.com/ProductDetail/ON-Semiconductor/15KE18ARL4G/
6.8Vz | £0.15 | Mouser | 1 | £0.15 | 1W; bowood no detail of values on site; CPC min 10; RS min 50 | http://uk.mouser.com/ProductDetail/Fairchild-Semiconductor/BZX85C6V8/
Misc | £0.00 | None
DIP-14-socket | £0.00 | Stock | 1 | £0.00
DIP-8-socket | £0.00 | Stock | 2 | £0.00
DIP-6-socket | £0.16 | RS | 6 | £0.98 | Min order 10 | http://uk.rs-online.com/web/p/products/6742426/
Power coaxial jack | £2.32 | Mouser | 1 | £2.32 |  | http://uk.mouser.com/ProductDetail/Kobiconn/163-4304-E/
Power mating plug | £0.98 | Mouser | 1 | £0.98 |  | http://uk.mouser.com/ProductDetail/Kobiconn/171-PA5521-1-E/
1A Fuse | £0.13 | Mouser | 5 | £0.65 | 5x20mm | http://uk.mouser.com/ProductDetail/Schurter/00341516/?qs=sGAEpiMZZMuMS2dUaCDnDFe1E5JCIxfJ
5x20mm fuse holder | £0.70 | Mouser | 1 | £0.70 |  | http://uk.mouser.com/ProductDetail/Schurter/86012010/?qs=sGAEpiMZZMtRmoYvq3OwzBxyed2Ii3ui0fQBNVYn1SY%3d
3.5mm stereo socket | £0.45 | Bowood | 2 | £0.90
BNC socket | £0.85 | Bowood | 6 | £5.10
1mH | £0.12 | CPC Farnell | 1 | £0.12 | Min order 5 | http://cpc.farnell.com/epcos/b78108s1105j/inductor-axial-1000uh/dp/FT01436
DPDT switch | £0.72 | CPC Farnell | 6 | £4.32 | for the attenuator | http://cpc.farnell.com/multicomp/1md1t1b1m1qe/switch-dpdt/dp/SW02853
T50-2 | £0.14 | GQRP | 7 | £1.01 | Join GQRP for 10 for 1.45
T50-6 | £0.22 | GQRP | 3 | £0.66 | Join GQRP for 10 for 2.20
V23105A5006A201 | £1.34 | Mouser | 7 | £9.38 |  | http://uk.mouser.com/ProductDetail/TE-Connectivity/V23105A5006A201/
PEC16-4020F-S0024 | £0.94 | Mouser | 1 | £0.94 |  | http://uk.mouser.com/ProductDetail/Bourns/PEC16-4020F-S0024/
100k log pot + switch | £0.63 | Mouser | 1 | £0.63 |  | http://uk.mouser.com/ProductDetail/BI-Technologies-TT-Electronics/P170S-FC15BR100K/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
M20-7821046 | £0.11 | Hobbytronics | 6 | £0.66 |  | http://www.hobbytronics.co.uk/cables-connectors/pcb-headers-sockets/header-female-1-10
TO-39 Heatsink | £0.30 | Bowood | 1 | £0.30
FB | £0.00 | Stock | 1 | £0.00
 |  |  | Grand Total | £57.12

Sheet: Resistor value for relay switch
Coil resistance (ohm) | Coil voltage (volts) | Coil current (amps) | Ic (mA) | Transistor Ic (mA) | Transistor Vceo (volts) | Transistor min hfe | Ib (amps)k(x2 for saturation) | Ib (mA) | R1 (ohms) | Std. Val. R1 (ohms) | Actual ib (amps) | Actual Ib (mA) | Transistor type
540 | 9 | 0.01666666667 | 16.666667 | 800 | 50 | 100 | 0.00033333 | 0.3333333333 | 15000 | 15000 | 0.0003333333333 | 0.3333333333 | 2N2222A
 |  |  |  | 100 | 30 | 110 | 0.00030303 | 0.303030303 | 16500 | 16000 | 0.0003125 | 0.3125 | BC548
Base switching voltage |  |  |  | 100 | 45 | 180 | 0.00018519 | 0.1851851852 | 27000 | 27000 | 0.0001851851852 | 0.1851851852 | BC547B
5

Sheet: Transistors
Common Transistor Characteristics
 | Ic (mA) | Vceo | Vcbo | hfe | @
BC546B | 100 | 65 | 80 | 290 | 2.0mA, 5V
BC547B | 100 | 45 | 50 | 290 | 2.0mA, 5V
BC548B | 100 | 30 | 30 | 290 | 2.0mA, 5V
BC107 | 200 | 45 | 50 | 110-450 | 2mA,5V
BC108 | 200 | 25 | 30 | 110-800 | 2mA,5V
BC109 | 200 | 25 | 30 | 200-800 | 2mA,5V
BFY50 | 1000 | 35 | 80 | 112 | 150mA, 10V
BFY51 | 1000 | 30 | 60 | 123 | 150mA, 10V
BFY52 | 1000 | 20 | 40 | 142 | 150mA, 10V
2N3866 | 400 | 30 | 55 | 10-200 | 50mA,5V
2N2905 | 600 | 40 | 60 | > 50 | 1mA, 10V
2N2222 | 800 | 50 | 75 | 75-325 | 1mA, 10V
 |  |  |  |  | l

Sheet: Delivery
 | Delivery | Min order
Bowood | UK delivery from £2.85 | £5.00
JAB | up to £10: £3.75, [£10.01 to £30] £2.90, over £30 Free
RS | Free | None
CPC | Free in May | None
Mouser | £12, free on order over £50
Rapid | £? Free on order over £30

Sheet: Other parts
EasiBuild Mark 2 Parts | Orig EB part | Mk2 part | Supplier | Cost | Quantity | Total | Notes | URL
V23105A5001A201 |  |  | RS | £1.45 | 0 | £0.00 | 5v, 150mW, out of stock
V23105A5476A201 |  |  | CPC | £1.25 | 0 | £0.00 | 12v, 400mW
3.5mm mono socket |  |  | Mouser | £0.62 |  | £0.00 |  | http://uk.mouser.com/ProductDetail/Kobiconn/16PJ138/
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

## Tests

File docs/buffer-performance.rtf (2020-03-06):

g3wce dds/buffer performance at each HF band
1.8 MHz (160m) - orig 1.838 MHz, bufout 1.819 dB - (1.785V to -1.886V) .tran 1m
22pF: 1.77V - -1.892V 1.891 dB
15pF: 1.22V - -1.299V -1.325 dB !!
10pF: 0.829V - -0.878V -4.774 dB !!
3.5 MHz (80m) - orig 3.56 MHz, bufout peak 4 MHz 4.109 dB (2.871V to -3.333V) .tran 100u
22pF: 2.891V - -3.238V 5.791 dB
15pF: 2.145V - -2.274V 2.795 dB
10pF: 1.465V - -1.527V -525.147mdB !!
7 MHz (40m) - orig 7.030 MHz, bufout 8.501 dB (3.117V to -4.612V) .tran 100u
22pF: 3.2V - -4.6V, 8.171 dB
15pF: 3.0V - -3.391V 6.799 dB
10pF: 2.230V - -2.360V 4.030 dB
10 MHz (30m) - orig 10.118 MHz, bufout peak 10.005 MHz, 8.878 dB (3.136V to -4.981V) .tran 1m
22pF: 3.178V - -4.987V 2.427 dB much noise
15pF: 3.074V - -3.765V 686.661 mdB ??!
10pF: 2.494V - -2.673V -1.954dB !!
14 MHz (20m) - orig 14.060 MHz, bufout peak 14.002 MHz, 9.079 dB (3.164V to -5.091V) .tran 100u
22pF: 3.1721V - -5.075V 9.312 dB
15pF: 3.036V - -3.911V 7.731 dB
10pF: 2.587V - -2.831V 5.377 dB
18 MHz (17m) - orig 18.096 MHz, bufout peak 18.002 MHz, 8.866 dB (3.046V to -5.128V)
22pF: 3.095V - -5.089V -9.429 dB !!
15pF: 2.942V - -3.937V -10.950 dB !!
10pF: 2.579V - -2.899V -13.110 dB !!
21 MHz (15m) - orig 21.054 MHz, bufout peak 21.008 MHz, 8.706 dB (2.997V to -5.041V)
24 MHz (12m) - orig 24.908 MHz, bufout peak 25.003 MHz, 8.352 dB (2.910V to -4.927V)
28 MHz (10m) - orig 28.060 MHz, bufout peak 28.008 MHz, 8.170 dB (2.800V to -4.777V) .tran 100u
22pF: 2.781V - -4.802V 7.833 dB
15pF: 2.676V - -3.817V 6.519 dB
10pF: 2.363V - -2.808V 4.535 dB

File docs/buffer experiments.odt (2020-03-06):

10pF coupling capacitor between DDS and buffer.

1.838MHz

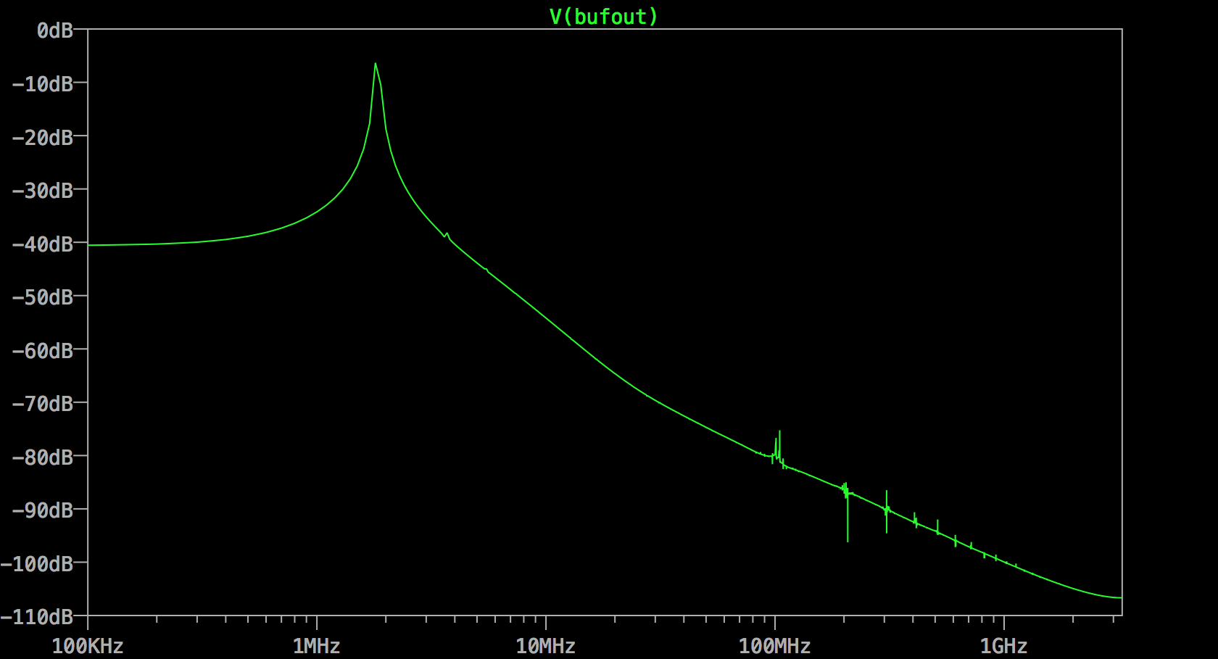
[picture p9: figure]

3.56MHz

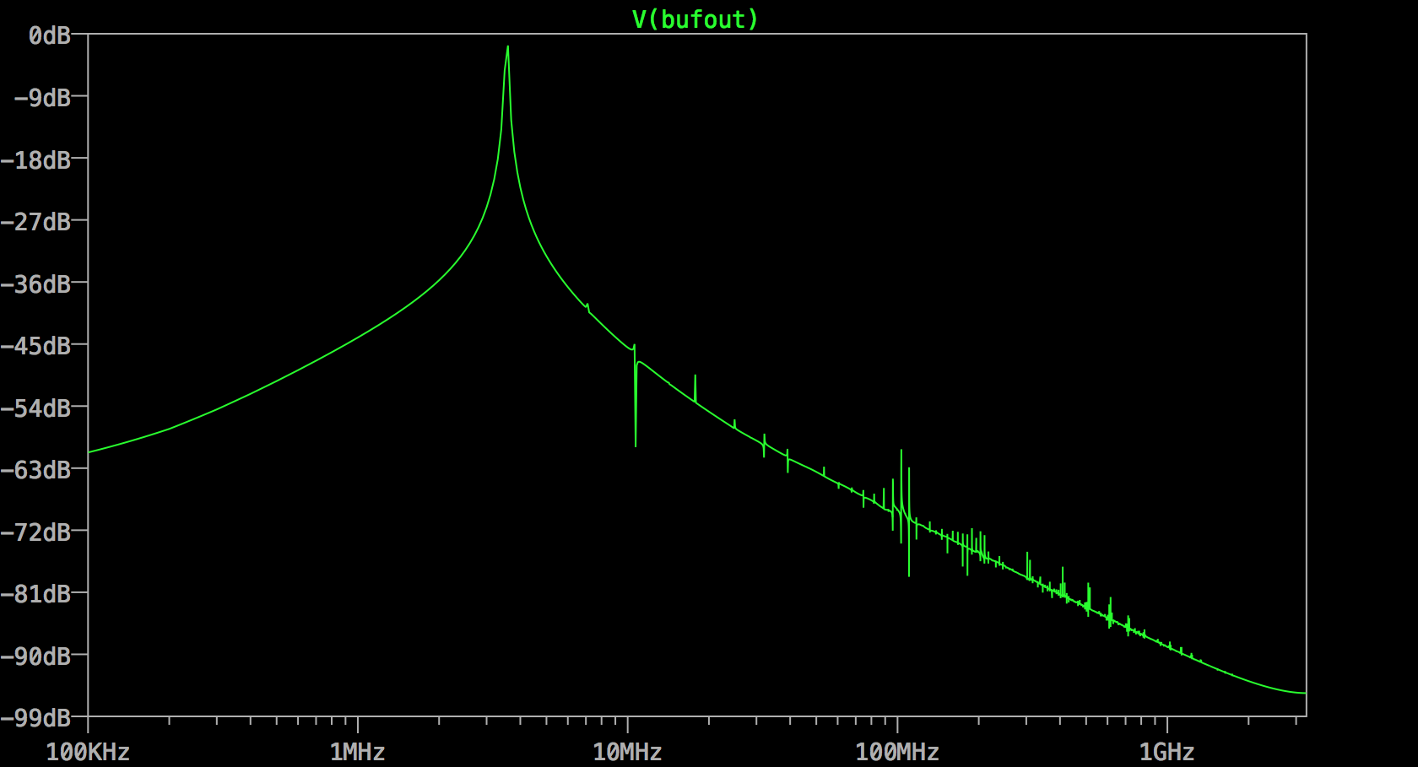
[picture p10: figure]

3.56MHz

10pF (.tran 100u): 232mdB – crap!

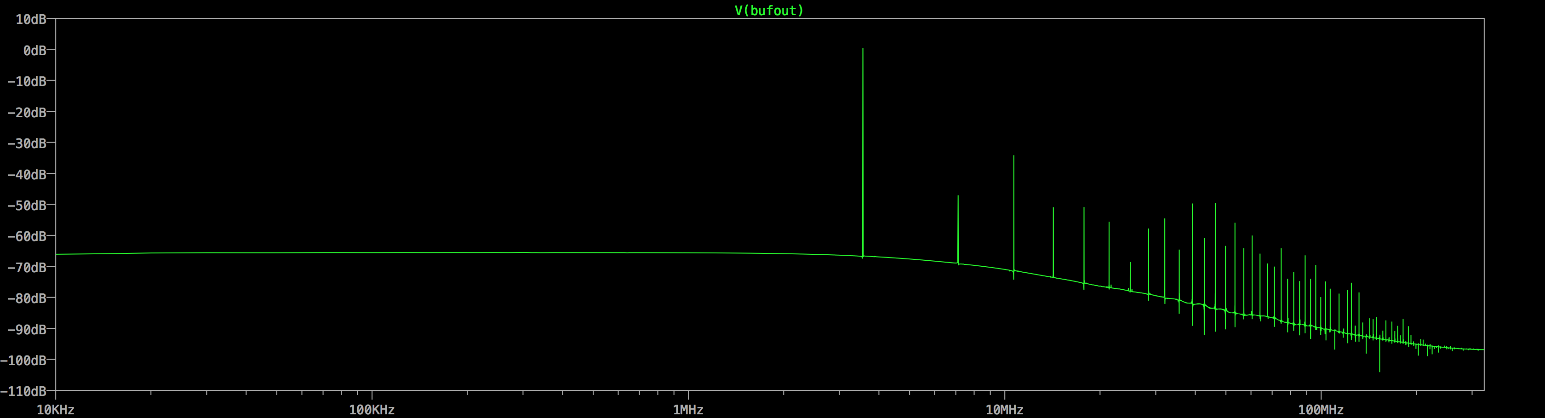
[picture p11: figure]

22pF (original) (.tran 100u): 6.550dB

The spectrum looks fine, and has decent signal.

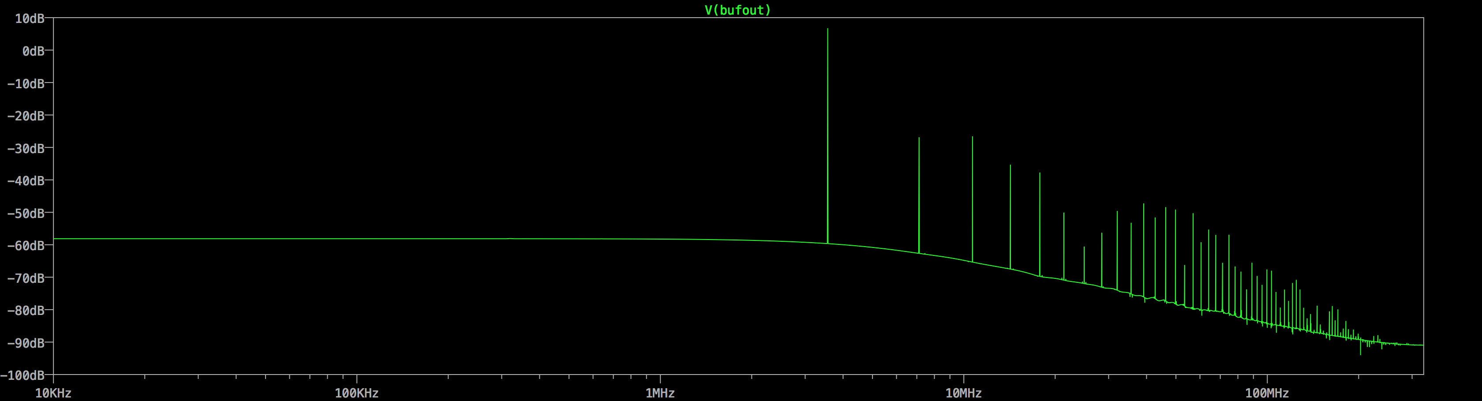
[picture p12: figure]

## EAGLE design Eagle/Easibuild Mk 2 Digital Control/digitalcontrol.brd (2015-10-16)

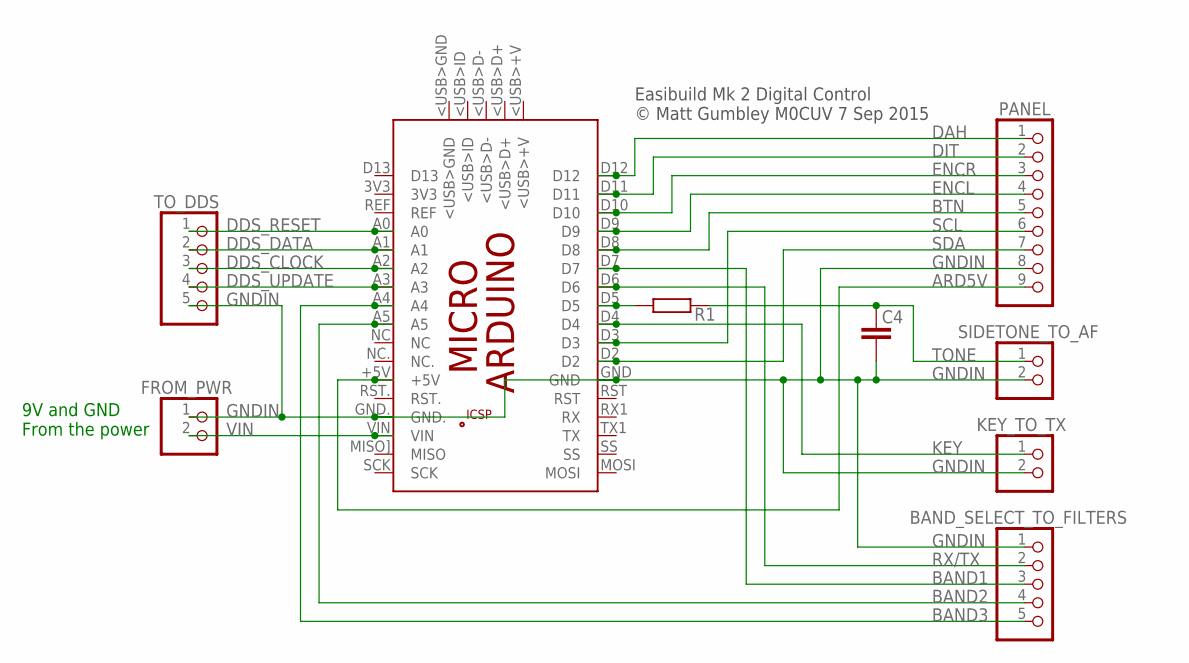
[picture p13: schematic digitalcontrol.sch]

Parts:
BAND_SELECT_TO_FILTERS: PINHD-1X5; 1X05
C4: C-EU050-025X075; C050-025X075
FROM_PWR: PINHD-1X2; 1X02
KEY_TO_TX: PINHD-1X2; 1X02
PANEL: PINHD-1X9; 1X09
PCB1: ARDUINO_MICRO
R1: R-EU_0204/5; 0204/5
SIDETONE_TO_AF: PINHD-1X2; 1X02
TO_DDS: PINHD-1X5; 1X05

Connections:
ARD5V: PANEL.9, PCB1.+5V
BAND1: BAND_SELECT_TO_FILTERS.3, PCB1.D7
BAND2: BAND_SELECT_TO_FILTERS.4, PCB1.A5
BAND3: BAND_SELECT_TO_FILTERS.5, PCB1.A4
BTN: PANEL.5, PCB1.D8
DAH: PANEL.1, PCB1.D12
DDS_CLOCK: PCB1.A2, TO_DDS.3
DDS_DATA: PCB1.A1, TO_DDS.2
DDS_RESET: PCB1.A0, TO_DDS.1
DDS_UPDATE: PCB1.A3, TO_DDS.4
DIT: PANEL.2, PCB1.D11
ENCL: PANEL.4, PCB1.D9
ENCR: PANEL.3, PCB1.D10
GNDIN: BAND_SELECT_TO_FILTERS.1, C4.2, FROM_PWR.1, KEY_TO_TX.2, PANEL.8, PCB1.GND, PCB1.GND., SIDETONE_TO_AF.2, TO_DDS.5
KEY: KEY_TO_TX.1, PCB1.D4
unnamed: PCB1.D5, R1.1
RX/TX: BAND_SELECT_TO_FILTERS.2, PCB1.D6
SCL: PANEL.6, PCB1.D3
SDA: PANEL.7, PCB1.D2
TONE: C4.1, R1.2, SIDETONE_TO_AF.1
VIN: FROM_PWR.2, PCB1.VIN

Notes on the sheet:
Easibuild Mk 2 Digital Control © Matt Gumbley M0CUV 7 Sep 2015
9V and GND From the power

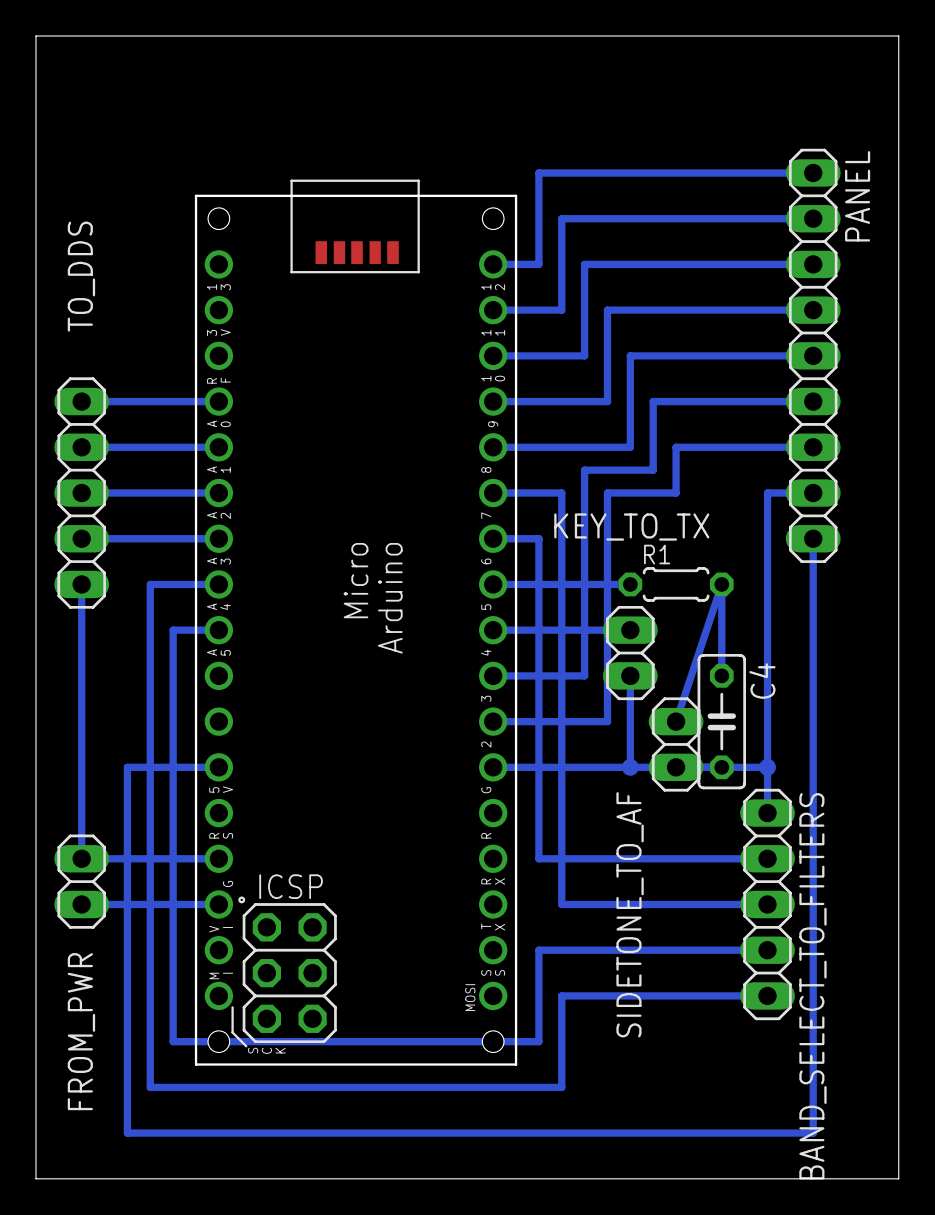
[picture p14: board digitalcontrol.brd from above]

Board: 1 copper layer, 47.9 x 63.5 mm, 9 parts (0 on the bottom side), 21 nets.

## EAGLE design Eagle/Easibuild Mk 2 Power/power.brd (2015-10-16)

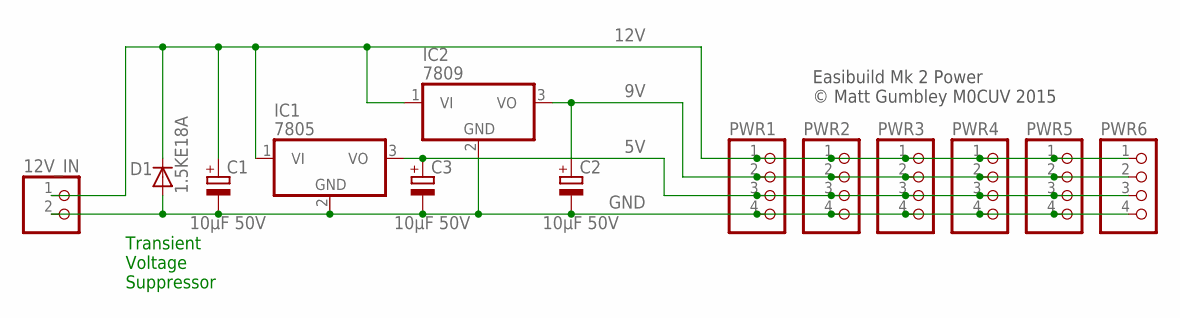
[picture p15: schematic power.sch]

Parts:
12V_IN: PINHD-1X2; 1X02
C1, C2, C3: 10μF 50V; E2,5-6E
D1: 1.5KE18A; C1702-254
IC1: 7805; TO220V
IC2: 7809; TO220V
PWR1, PWR2, PWR3, PWR4, PWR5, PWR6: PINHD-1X4; 1X04

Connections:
5V: C3.+, IC1.3 (VO), PWR1.3, PWR2.3, PWR3.3, PWR4.3, PWR5.3, PWR6.3
9V: C2.+, IC2.3 (VO), PWR1.2, PWR2.2, PWR3.2, PWR4.2, PWR5.2, PWR6.2
12V: 12V_IN.1, C1.+, D1.C, IC1.1 (VI), IC2.1 (VI), PWR1.1, PWR2.1, PWR3.1, PWR4.1, PWR5.1, PWR6.1
GND: 12V_IN.2, C1.-, C2.-, C3.-, D1.A, IC1.2 (GND), IC2.2 (GND), PWR1.4, PWR2.4, PWR3.4, PWR4.4, PWR5.4, PWR6.4

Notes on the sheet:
Transient Voltage Suppressor
Easibuild Mk 2 Power © Matt Gumbley M0CUV 2015

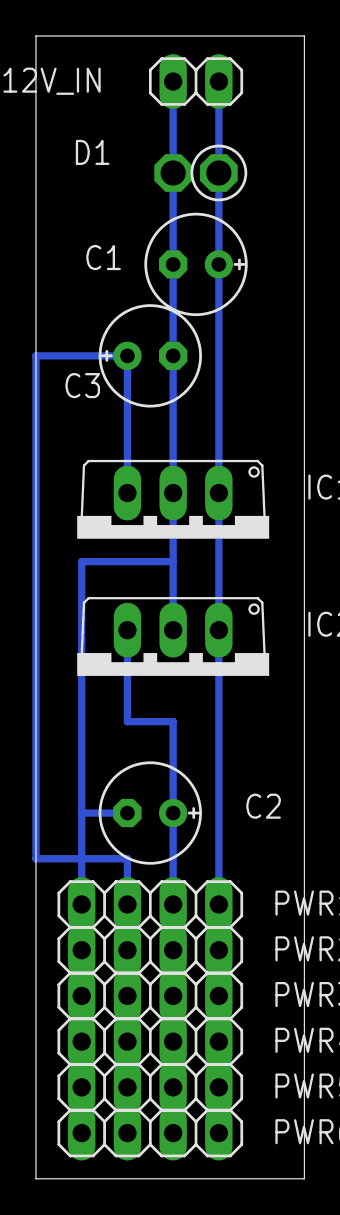
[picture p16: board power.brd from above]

Board: 2 copper layers, 14.9 x 63.5 mm, 13 parts (0 on the bottom side), 4 nets.

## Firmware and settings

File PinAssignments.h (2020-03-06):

// EasiBuild Mk 2 Firmware
// Author: Matt Gumbley M0CUV <matt.gumbley@devzendo.org>
//
// For Arduino Micro. If you want to target a different board, search for the comments 'CHANGE_BOARD';
// if you want to change the pins used for the various inputs/outputs, search for the comments 'CHANGE_PIN'.

#ifndef _PIN_ASSIGNMENTS_H_
#define _PIN_ASSIGNMENTS_H_

// CHANGE_PINS
// Right-hand side of Arduino Micro...
// Input pins are all on PINB or PIND for rapid reading in the interrupt service routine.
const int dahIn = 12; // PIND - am I sure about this? PINB is digital pin 8 to 13?
const int dahBit = 0x08;

const int ditIn = 11; // PINB
const int ditBit = 0x80;

const int encrIn = 10;// PINB
const int encrBit = 0x20;

const int enclIn = 9; // PINB
const int enclBit = 0x40;

const int btnIn = 8;  // PINB
const int btnBit = 0x10; // sure about this? isn't this 0x01?

const int band1Out = 7;
const int rxtxOut = 6;
const int sidetoneOut = 5;  // PWM, with RC low-pass filter network to convert
                            // to analogue. On OCR3A, PWM phase correct.
const int keyOut = 4;
// display is on 2 and 3, i2c.

const int internalLed = 13;

// Left-hand side of Arduino Micro...
const int ddsResetOut = 18;
const int ddsDataOut = 19;
const int ddsUpdateOut = 20;
const int ddsClockOut = 21;
const int band3Out = 22;
const int band2Out = 23;

inline uint16_t readPins() {
    return (PINB & 0xF0) | ((PIND & 0x40) >> 3);
}

// input change detection, called in loop() for test harness, or in ISR
uint16_t oldPins;
uint16_t newPins;
uint16_t initialPins;

void setupPins() {
    pinMode(dahIn, INPUT_PULLUP);
    pinMode(ditIn, INPUT_PULLUP);
    pinMode(encrIn, INPUT_PULLUP);
    pinMode(enclIn, INPUT_PULLUP);
    pinMode(btnIn, INPUT_PULLUP);

    pinMode(internalLed, OUTPUT);
    
    pinMode(band1Out, OUTPUT);
    pinMode(band2Out, OUTPUT);
    pinMode(band3Out, OUTPUT);

    pinMode(rxtxOut, OUTPUT); 
    pinMode(keyOut, OUTPUT);
    
    pinMode(ddsClockOut, OUTPUT);
    pinMode(ddsUpdateOut, OUTPUT);
    pinMode(ddsDataOut, OUTPUT);
    pinMode(ddsResetOut, OUTPUT);

    initialPins = oldPins = newPins = readPins();
}

#endif

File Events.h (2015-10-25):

// EasiBuild Mk 2 Firmware: event definitions
// Author: Matt Gumbley M0CUV <matt.gumbley@devzendo.org>
//
// Acknowledgements: Jack Ganssle for his article on firmware debouncing
// http://www.ganssle.com/debouncing-pt2.htm
//
// Rotary encoder reading from an article at
// http://makeatronics.blogspot.co.uk/2013/02/efficiently-reading-quadrature-with.html


#ifndef _EVENTS_H_
#define _EVENTS_H_

const int evOff        = 0x00; // all buttons/key/paddle
const int evOn         = 0x01; // all buttons/key/paddle
const int evMedium     = 0x02; // button only medium press
const int evHard       = 0x03; // button only longer press
const int evStateMask  = evOff | evOn | evMedium | evHard;

const int evDah        = 0x80; // off, on
const int evDit        = 0x40; // off, on
const int evBtn        = 0x20; // off, on, medium, hard
const int evButtonMask = evDah | evDit | evBtn;

const int evLeft       = 0x10;
const int evRight      = 0x08;
const int evEncoderMask = evLeft | evRight;

const int evFast       = 0x01; // rotary encoder normal events
const int evSlow       = 0x02; // rotary envoder damped events
const int evSpeedMask  = evFast | evSlow;

const int evTimerTick  = 0x04;

const int evTypeMask   = evDah | evDit | evBtn | evLeft | evRight | evTimerTick;

defineFifo(eventFifo, int, 100)

defineTimerRun(eventQueueingTimer, 0) {
    static int tickEvent = evTimerTick;
    eventFifo.put(&tickEvent);
}

static char zut[20];
inline void eventOccurred(int eventCode) {
    sprintf(zut, ">ev:0x%04X", eventCode);
    Serial.println(zut);
    if (!eventFifo.put(&eventCode)) {
        Serial.println("FIFO overrun");
    }
}

class Damper {
public:
    Damper(int tickDelay) {
        delayLimit = tickDelay;
        reset();
    }

    void reset() {
        delay = delayLimit >> 1;
    }
    
    bool left() {
        if (delay == 0) {
            delay = delayLimit;
            return true;
        } else {
            delay--;
            return false;
        }
    }
    
    bool right() {
        if (delay == delayLimit) {
            delay = 0;
            return true;
        } else {
            delay++;
            return false;
        }
    }
private:
    int delayLimit;
    int delay;
};

class PressDurationDetector {
public:
    // Called every checkMsec, to update internal timer count.
    // returns evOff if no press in progress, or
    // evMedium, evHard for longer presses
    int longPressDetected() {
        if (!keyState) {
            return evOff;
        }
        switch (ticksSincePressed++) {
            case 125: 
                return evMedium; // 500ms after press
            case 500:
                keyState = false; // to prevent overflow if button held in for a long time
                return evHard;   // 2000ms after press
        }
        return evOff;
    }
    
    // Called whenever the debounced key state changes.
    void keyStateChanged(bool pressed) {
        keyState = pressed;
        ticksSincePressed = 0;
    }

private:
    bool keyState = false;
    int ticksSincePressed = 0;
};

// Based on code by Jack Ganssle.
const uint8_t checkMsec = 4;     // Read hardware every so many milliseconds
const uint8_t pressMsec = 10;    // Stable time before registering pressed
const uint8_t releaseMsec = 100; // Stable time before registering released

class Debouncer {
public:
    // called every checkMsec.
    // The key state is +5v=released, 0v=pressed; there are pullup resistors.
    void debounce(bool rawPinState) {
        bool rawState;
        keyChanged = false;
        keyReleased = debouncedKeyPress;
        if (rawPinState == debouncedKeyPress) {
            // Set the timer which allows a change from current state
            resetTimer();
        } else {
            // key has changed - wait for new state to become stable
            debouncedKeyPress = rawPinState;
            keyChanged = true;
            keyReleased = debouncedKeyPress;
            // And reset the timer
            resetTimer();
        }
    }

    // Signals the key has changed from open to closed, or the reverse.
    bool keyChanged;
    // The current debounced state of the key.
    bool keyReleased;

private:
    void resetTimer() {
        if (debouncedKeyPress) {
            count = releaseMsec / checkMsec;
        } else {
            count = pressMsec / checkMsec;
        }
    }

    uint8_t count = releaseMsec / checkMsec;
    // This holds the debounced state of the key.
    bool debouncedKeyPress = false; 
};

Debouncer ditDebounce;
Debouncer dahDebounce;
Debouncer btnDebounce;
PressDurationDetector pressDurationDetector;
Damper damper(10);
static int8_t encoderLookupTable[] = {
    0, -1, 1, 0, 1, 0, 0, -1, -1, 0, 0, 1, 0, 1, -1, 0
};
static uint8_t encoderValue = 0;

// input change to event conversion, called in loop or ISR
void eventDecode(uint16_t rawPins) {
    // Do the decoding, and call eventOccurred with each event found...
    // Need to debounce dit/dah, not so bad on encoder button.
    ditDebounce.debounce(rawPins & ditBit);
    if (ditDebounce.keyChanged) {
        eventOccurred(evDit | (ditDebounce.keyReleased ? evOff : evOn));
    }

    dahDebounce.debounce(rawPins & dahBit);
    if (dahDebounce.keyChanged) {
        eventOccurred(evDah | (dahDebounce.keyReleased ? evOff : evOn));
    }

    switch (pressDurationDetector.longPressDetected()) {
        case evMedium: eventOccurred(evBtn | evMedium); break;
        case evHard: eventOccurred(evBtn | evHard); break;
    }
    btnDebounce.debounce(rawPins & btnBit);
    if (btnDebounce.keyChanged) {
        bool pressed = !btnDebounce.keyReleased;
        pressDurationDetector.keyStateChanged(pressed);
        if (pressed) {
            damper.reset();
        }
        eventOccurred(evBtn | (pressed ? evOn : evOff));
    }

    // rotary encoder....
    encoderValue = encoderValue << 2;
    encoderValue = encoderValue | ((rawPins & (enclBit | encrBit)) >> 5);
    switch (encoderLookupTable[encoderValue & 0b1111]) {
        case 0:
            break;
        case 1:
            eventOccurred(evLeft | evFast);
            if (damper.left()) {
                eventOccurred(evLeft | evSlow);
            }
            break;
        case -1:
            eventOccurred(evRight | evFast);
            if (damper.right()) {
                eventOccurred(evRight | evSlow);
            }
            break;
    }
}

#endif

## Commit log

2015-06-28 Added SCoop, Sine generation, waveform shaping, pin initialisation and main loop that should toggle shaped sinewave. Not yet tested on hardware.
2015-07-02 Switch to sidetone generation using Martin Nawrath's DDS sine wave generator
2015-09-21 The completed power board & schematic.
2015-09-21 What the prototype board looks like.
2015-09-22 Renamed the power board/schematic graphics.
2015-09-22 Add the parts list & other Excel calculations.
    [Parts List.xlsx]
2015-09-22 The power board on the breadboard.
2015-09-23 The digital control board schematic, and Arduino Micro pinout (from https://github.com/Bouni/Arduino-Pinout).
2015-09-26 The digital control board layout.
2015-09-28 Pictures of the control board.
2015-09-29 Move out the sidetone oscillator code.
    [EasiBuildMk2.ino]
2015-09-29 Extract pin I/O and pullup resistor settings to a function.
2015-10-08 Add libraries: enable interrupt, LiquidCrystal, SCoop
2015-10-09 Add notes on installing libraries into the Arduino IDE.
2015-10-16 Add Eagle files for the power board
    [power.brd, power.sch]
2015-10-16 Add Eagle files for the digital control board (this version has one of the input pins on port d, not port b)
    [digitalcontrol.brd, digitalcontrol.sch]
2015-10-17 Use PINB and PIND for the input pins. Can't use pin change interrupt to sense DAH, so will use a timer to sample pins.
2015-10-17 Extract pin change sensing.
2015-10-17 Bugfix on inputs test harness.
    [Events.h, PinAssignments.h]
2015-10-17 Now using camelCase for everything… Events test harness, and pin change to event translation (need deb ounce).
2015-10-17 Event handling under 4ms timer control (along with sidetone generation). Test harness writes to serial under timer ISR, which needs decoupling with Scoop.
2015-10-17 Now with rotary encoder decoding!
2015-10-18 Sidetone oscillator control test harness.
    [EasiBuildMk2.ino]
2015-10-19 Need to invert this state - need to rename it, for clarity: pins are inverted.
    [Events.h]
2015-10-19 Invert sense of debunker.
    [Events.h]
2015-10-19 Fast and slow rotary encoder events. Trying to determine cause of strange event codes that occur in the output test harness.
2015-10-20 Some of these pin assignments were wrong...
    [PinAssignments.h]
2015-10-21 Pullup resistors mean that inputs are 1=released, 0=pressed. Make note of that.
2015-10-21 Auto loop through the outputs, to help diagnose problems when I have no control board attached - just USB serial monitor.
2015-10-21 The pins have changed their order on the schematic, so reorder them in the test harness.
2015-10-23 Correct the left-hand side output pins, with reference to the SDK header. Was working from an incorrect pin mapping diagram.
    [PinAssignments.h]
2015-10-23 Not using enable interrupt library, as I'm sampling all inputs in a timer.
2015-10-23 Fix ridiculous error. D'oh. Types, for the win...
    [EasiBuildMk2.ino]
2015-10-24 Set the internal LED to output on startup. Will this cause the weak LED on external power-on (not USB) to go away?
2015-10-25 Added a single timer tick event that can be triggered.
2015-10-28 Add two Eagle component modules for the Arduino and DDS. Thanks to element14 and Johan Adlers.
2015-10-28 Added the DDS/Buffer board and schematic images.
2015-10-29 Updated control board schematic with values, and rendered at 300dpi
2015-10-29 Get the value and name of the capacitor right, at 300dpi.
2015-10-30 Updated DDS board and schematic with attribution.
2015-11-03 Add schematic of DDS module, from N3ZI http://www.pongrance.com/DDS-9850.html Add AD9850 data sheet.
2015-11-28 Add the N0SS Noise Source schematic and board layout.
2020-03-06 Ensure latest local changes are captured before moving to github.
    [Parts List.xlsx]
